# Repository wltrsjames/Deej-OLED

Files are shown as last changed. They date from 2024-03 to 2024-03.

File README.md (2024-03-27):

Deej project: https://github.com/omriharel/deej/

## Yet another volume mixer, but with some cool features

 - 5 volume faders
 - 5 mute buttons, that can double as HID buttons to trigger hotkeys at the OS level, each button is also kitted with an LED indicator
 - 1 master volume pot
 - An OLED screen that displays random monochrome 'gif' animations and give feedback on the volume levels
 - Volume levels disappear after 5 seconds so you can see your beautiful animations 
 
 Here's mine:




## Parts list

 - Teensy 4.0
 - Linear faders: 10K, 60 mm: (https://www.amazon.co.uk/gp/product/B07PNDLKQQ/ref=ppx_yo_dt_b_search_asin_image?ie=UTF8&psc=1)
 - Master volume pot: 
https://www.amazon.co.uk/gp/product/B0734K6WYP/ref=ppx_yo_dt_b_search_asin_image?ie=UTF8
- OLED screen: 
https://www.amazon.co.uk/gp/product/B08LYL7QFQ/ref=ppx_yo_dt_b_search_asin_title?ie=UTF8&psc=1
- Clear keycaps:
https://www.amazon.co.uk/gp/product/B08831GTXS/ref=ppx_yo_dt_b_asin_title_o07_s00?ie=UTF8&psc=1
- M3 inserts:
https://www.amazon.co.uk/gp/product/B089GNXKKV/ref=ppx_yo_dt_b_asin_title_o06_s03?ie=UTF8&psc=1
- Fader sliders:
https://www.amazon.co.uk/gp/product/B07W78R5T9/ref=ppx_yo_dt_b_asin_title_o06_s03?ie=UTF8
- Proto board - HOLE SPACING IS IMPORTANT
https://www.amazon.co.uk/gp/product/B08151V9TS/ref=ppx_yo_dt_b_asin_title_o06_s00?ie=UTF8&th=1
- Red LEDs:
https://www.amazon.co.uk/gp/product/B00WX39R3S/ref=ppx_yo_dt_b_asin_title_o05_s00?ie=UTF8&psc=1
- Large Pot control knob:
https://www.amazon.co.uk/gp/product/B089D4H55W/ref=ppx_yo_dt_b_asin_title_o06_s00?ie=UTF8&psc=1
- M2 nylon standoffs
https://www.amazon.co.uk/Spacers-Standoff-Assortment-Threaded-Circuit/dp/B09F9PHKJ6/ref=sr_1_5?sr=8-5
-rubber feet
-M2 countersank screws

## Assembly

Fix the OLD screen to inside of the box with M2 screws and female nylon standoffs, the master pot is held in place with it's provided nut.
The faders are also held in place with M2 screws.



In the case of the teensy 4.0 all of the analogue pots run off of 3v, the OLED screen and the LEDs are running off of the 5v pin.

The Teensy has to be soldered to a protoboard with the correct holes and mounted at the correct height on the box cover

This allows for the correct clearance for the USB port 
 
The microcontroller is mounted to the lid via m2 nylon screws and standoffs, add rubber feet so the screws don't make contact with your desk


Pinouts:
| Pin | Function |
|--|--|
| A0 | Master volume dial |
| A1 | Fader 1 |
| A6 | Fader 2 |
| A3 | Fader 3 |
| A7 | Fader 4 |
| A8 | Fader 5 |
| A4 | SDA OLED screen|
| A5 | SCL OLED screen |
| D8 | Mute button 1 |
| D9 | Mute button 2 |
| D11 | Mute button 3 |
| D10 | Mute button 4 |
| D4 | Mute LED 1 |
| D5 | Mute LED 2 |
| D2 | Mute LED 3 |
| D3 | Mute LED 4 |
| D6 | Mute LED 5 |

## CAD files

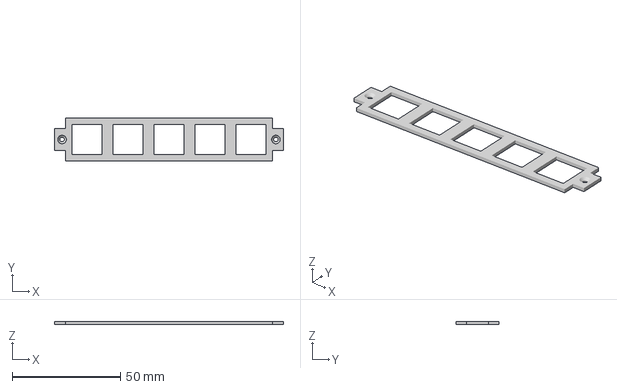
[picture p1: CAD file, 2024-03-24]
3dPrints/DeejNuts-switchPlate.3mf
106.0 x 20.0 x 1.50 mm

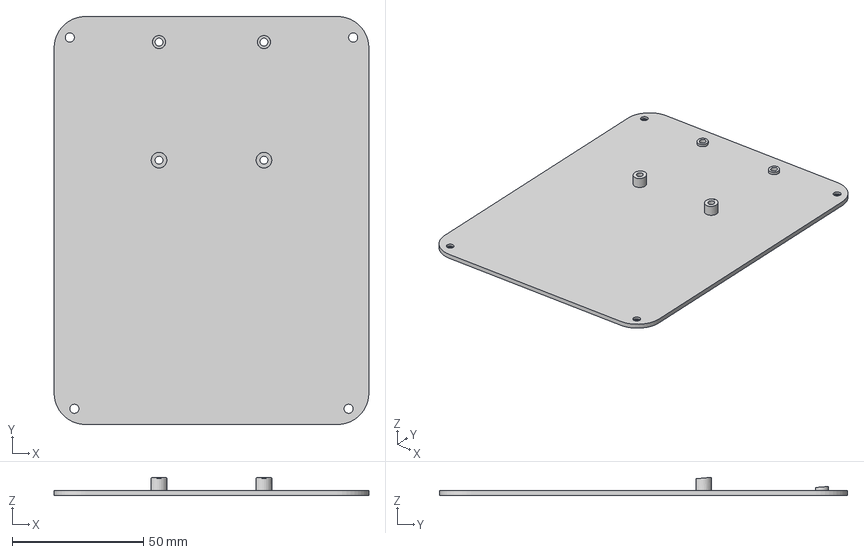
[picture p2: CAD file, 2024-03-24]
3dPrints/DeejNuts-Cover.3mf
120.0 x 155.5 x 7.00 mm

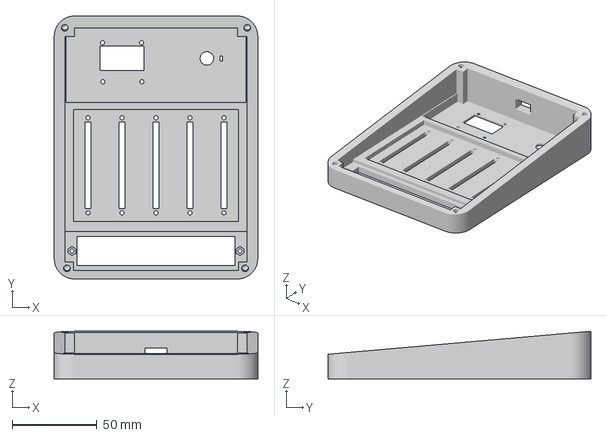
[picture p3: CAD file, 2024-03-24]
3dPrints/DeejNuts-base.3mf
120.0 x 155.0 x 28.0 mm

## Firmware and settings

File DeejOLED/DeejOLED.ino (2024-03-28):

#include "Animations.h"
#include "OLED_init.h"

#include <Keyboard.h>

const int NUM_SLIDERS = 6;
const char *inputLabels[NUM_SLIDERS] = { "Master", "Discord", "Browser", "Music", "Current App", "Mic" };
// make sure each hotkey combo ends with 0
const int hotKeys[][3] = { { 0 }, { 0 }, { 0 }, { 0 }, { KEY_LEFT_CTRL, KEY_F12, 0 } };

//if starting up
boolean startUp = true;
//if an input has been adjusted
boolean inputAdjusted = false;
//if the ui countdown timer to clear it has restarted
boolean uiTimerRestarted = true;

//counter to work out how long the vol slider has been onscreen
unsigned long previousMillis = 0;
//counter to work out how animation framerate
unsigned long previousAnimationMillis = 0;
//how many milliseconds the vol slider should be onscreen
unsigned long volumeSliderTimeout = 3000;
//rng storage
int randNumber;

//POT info
const int analogInputs[NUM_SLIDERS] = { A0, A1, A6, A3, A7, A8 };

const int NUM_BUTTONS = 5;
const int digitalInputs[NUM_BUTTONS] = { 8, 9, 11, 10, 7 };
const int ledPins[NUM_BUTTONS] = { 4, 5, 2, 3, 6 };

//storage of analog inputs
int analogSliderValues[NUM_SLIDERS];
int filteredSliderValues[NUM_SLIDERS];

//indicator as to which input was last changed
int lastChangedInput;
//sets the amount of cycles until the input is read for analog inputs
const int noiseGate = 2;

bool buttonState[NUM_BUTTONS] = { 0, 0, 0, 0, 0 };
bool ledState[NUM_BUTTONS] = { 0, 0, 0, 0, 0 };

void setup() {
  Serial.begin(9600);
  randomSeed(analogRead(A4));

  Keyboard.begin();
  if (!display.begin(SSD1306_SWITCHCAPVCC, SCREEN_ADDRESS)) {
    Serial.println(F("SSD1306 allocation failed"));
    for (;;)
      ;  // Don't proceed, loop forever
  }

  // init buttons
  for (int i = 0; i < NUM_BUTTONS; i++) {
    pinMode(digitalInputs[i], INPUT_PULLUP);
  }

  // init leds
  for (int i = 0; i < NUM_BUTTONS; i++) {
    pinMode(ledPins[i], OUTPUT);
    digitalWrite(ledPins[i], HIGH);
  }

  //init pots
  for (int i = 0; i < NUM_SLIDERS - 2; i++) {
    pinMode(analogInputs[i], INPUT);
  }

  drawAnimation(chickenAnimation, chickenAnimationLength, true, 10, 1, false, (char *)"Deej OLED");

  // turn off all lights
  for (int i = 0; i < NUM_SLIDERS - 2; i++) {
    digitalWrite(ledPins[i], LOW);
  }
}

void loop() {
  randNumber = random(0, 8);

  switch (randNumber) {
    case 1:
      drawAnimation(spaceAnimation, spaceAnimationLength, true, 10, 10, true, "");
      break;
    case 2:
      drawAnimation(penguinAnimation, penguinAnimationLength, true, 40, 20, true, "");
      break;
    case 3:
      drawAnimation(chickenAnimation, chickenAnimationLength, true, 20, 5, true, "");
      break;
    case 4:
      drawAnimation(climbAnimation, climbAnimationLength, true, 40, 20, true, "");
      break;
    case 5:
      drawAnimation(diveAnimation, diveAnimationLength, true, 30, 20, true, "");
      break;
    case 6:
      drawAnimation(spiral1Animation, spiral1AnimationLength, true, 40, 20, true, "");
      break;
    case 7:
      drawAnimation(spiral2Animation, spiral2AnimationLength, true, 40, 20, true, "");
      break;
  }
}

void drawAnimation(const unsigned char animation[][1024], int totalFrames, bool invertColours, unsigned long frameTime, int totalLoops, boolean adjustSliderValues, String message) {
  display.invertDisplay(invertColours);
  for (int loop = 0; loop < totalLoops; loop++) {
    for (int frame = 0; frame < totalFrames; frame++) {
      readButtons();

      //update and send the slider values in the render loop for optomisation
      if (adjustSliderValues) {
        updateSliderValues();
        sendSliderValues();
      }

      //set frameRate
      unsigned long currentMillis = millis();
      if (currentMillis - previousAnimationMillis > frameTime) {
        previousAnimationMillis = currentMillis;
        display.clearDisplay();

        if (inputAdjusted) {
          display.drawBitmap(0, 0, animation[frame], SCREEN_WIDTH, SCREEN_HEIGHT / 2, 1);
          drawVolume();
        } else if (message.length() > 1) {
          display.drawBitmap(0, 0, animation[frame], SCREEN_WIDTH, SCREEN_HEIGHT / 4 * 3, 1);
          drawMessage(message);
        } else {
          display.drawBitmap(0, 0, animation[frame], SCREEN_WIDTH, SCREEN_HEIGHT, 1);
        }

        display.display();
      } else {
        //if no frame is drawn, redraw it
        frame--;
      }
    }
  }
}

void drawVolume() {
  display.fillRect(0, SCREEN_HEIGHT / 2, SCREEN_WIDTH, SCREEN_HEIGHT / 2, 0xFF);
  display.drawRect(0, SCREEN_HEIGHT / 2, SCREEN_WIDTH, SCREEN_HEIGHT / 2, 0x00);
  display.setTextSize(1);                       // Normal 1:1 pixel scale
  display.setTextColor(0x00);                   // Draw white text
  display.setCursor(3, SCREEN_HEIGHT / 2 + 2);  // Start at top-left corner
  display.println(F(inputLabels[lastChangedInput]));
  display.drawRect(4, SCREEN_HEIGHT / 2 + 15, SCREEN_WIDTH - 8, SCREEN_HEIGHT / 5, 0x00);
  display.fillRect(4, SCREEN_HEIGHT / 2 + 15, (map(filteredSliderValues[lastChangedInput], 0, 100, 0, SCREEN_WIDTH - 8)), SCREEN_HEIGHT / 5, 0x00);
}

void drawMessage(String message) {
  display.fillRect(0, SCREEN_HEIGHT / 4 * 3, SCREEN_WIDTH, SCREEN_HEIGHT / 4, 0xFF);
  //  display.drawRect(0, SCREEN_HEIGHT/2, SCREEN_WIDTH, SCREEN_HEIGHT/2, 0x00);
  display.setTextSize(1);                           // Normal 1:1 pixel scale
  display.setTextColor(0x00);                       // Draw white text
  display.setCursor(3, SCREEN_HEIGHT / 4 * 3 + 5);  // Start at top-left corner
  display.println(message);
}

void updateSliderValues() {
  for (int i = 0; i < NUM_SLIDERS; i++) {
    int lastValue = filteredSliderValues[i];
    int filteredValue;

    if (i != 0 && ledState[i - 1]) {
      filteredSliderValues[i] = 0;
      filteredValue = 0;
      analogSliderValues[i] = 0;
    } else {
      int currentValue = map(analogRead(analogInputs[i]), 1023, 0, 0, 1023);
      analogSliderValues[i] = currentValue;
      filteredValue = map(currentValue, 0, 1023, 0, 100);
    }

    int diff = lastValue - filteredValue;

    //if the filtered value has changed and has changed by the noise gate
    if (lastValue != filteredValue && (diff >= noiseGate || diff <= -noiseGate)) {
      if (!startUp) {
        inputAdjusted = true;
      }
      filteredSliderValues[i] = filteredValue;
      lastChangedInput = i;
      uiTimerRestarted = true;
    } else {
      uiTimer();
    }
  }
  startUp = false;
}

void uiTimer() {
  unsigned long currentMillis = millis();
  if (uiTimerRestarted) {
    uiTimerRestarted = false;
    previousMillis = millis();
  }

  if (currentMillis - previousMillis > volumeSliderTimeout) {
    inputAdjusted = false;
    uiTimerRestarted = true;
  }
}

void printSliderValues() {
  for (int i = 0; i < NUM_SLIDERS; i++) {
    String printedString = String("Slider #") + String(i + 1) + String(": ") + String(analogSliderValues[i]) + String(" mV");
    Serial.write(printedString.c_str());

    if (i < NUM_SLIDERS - 1) {
      Serial.write(" | ");
    } else {
      Serial.write("\n");
    }
  }
}

void sendSliderValues() {
  String builtString = String("");

  for (int i = 0; i < NUM_SLIDERS; i++) {
    builtString += String((int)analogSliderValues[i]);

    if (i < NUM_SLIDERS - 1) {
      builtString += String("|");
    }
  }

  Serial.println(builtString);
}

void readButtons() {
  for (int i = 0; i < NUM_BUTTONS; i++) {
    bool lastButtonState = buttonState[i];
    buttonState[i] = !digitalRead(digitalInputs[i]);

    if (!lastButtonState && buttonState[i]) {
      ledState[i] = !ledState[i];

      const int* hotKeyCombo = hotKeys[i];
      const int hotKeyComboLength = sizeof (hotKeyCombo[0]);

      for (int j = 0; j < hotKeyComboLength; j++) {
        if (hotKeyCombo[j] == 0) {
          delay(100);
          Keyboard.releaseAll();
          break;
        };
        Keyboard.press(hotKeyCombo[j]);
      }
    }

    if (ledState[i]) {
      digitalWrite(ledPins[i], HIGH);
    } else {
      digitalWrite(ledPins[i], LOW);
    }
  }
}
